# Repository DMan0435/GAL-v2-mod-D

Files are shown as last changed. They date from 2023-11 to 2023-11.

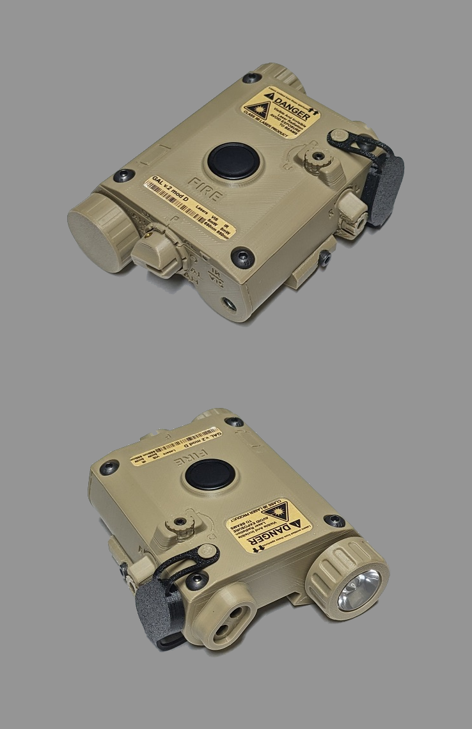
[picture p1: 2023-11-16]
IMAGES/GAL_v2 mod d 1.png

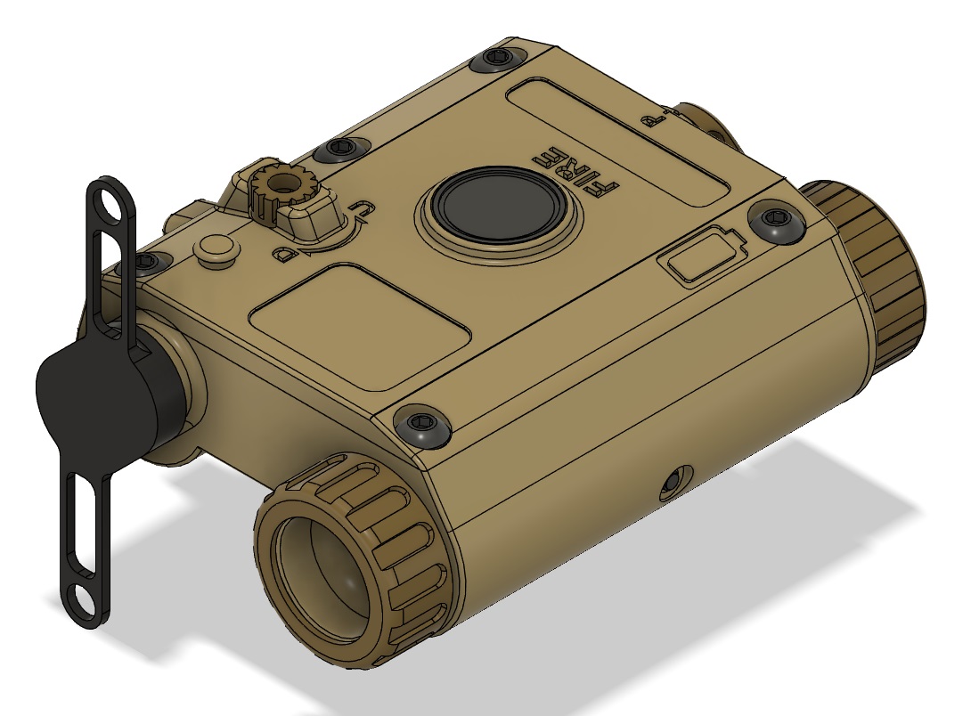
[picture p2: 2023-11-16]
IMAGES/img3.jpg

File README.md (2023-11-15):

# GAL-v2-mod-D

This is a modification of Knack Tactical's GAL V2 LAM project, found here: https://github.com/knack-tactical/GAL

This version requires several different components to be built, and custom 3D printed models found here.  Read the parts list and build guide documents for information on what you need.  If you have Knack's parts kit, many of the included parts can be used in this design as well.

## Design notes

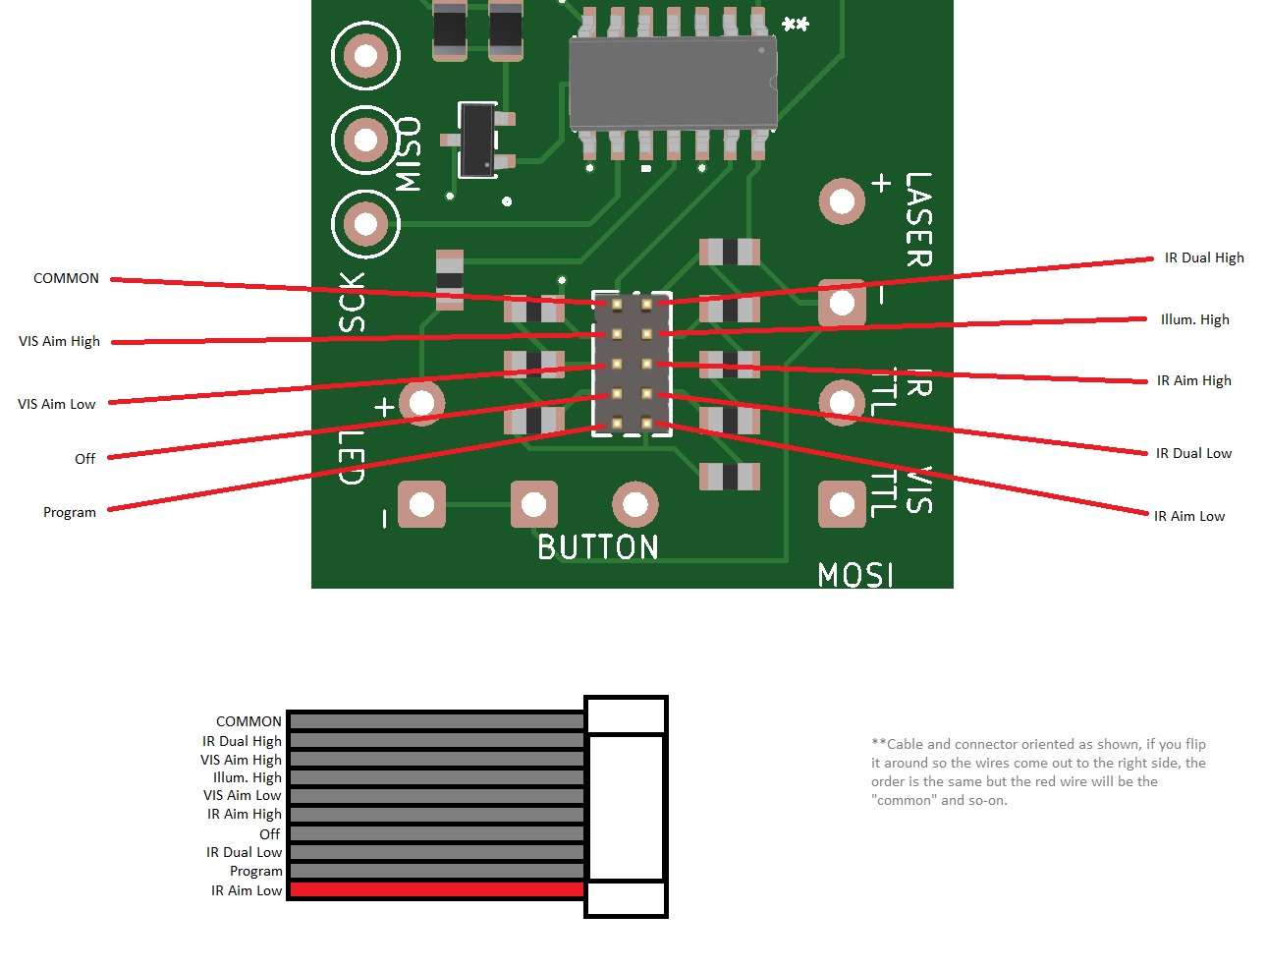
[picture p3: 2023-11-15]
PCB/GALv2modD_Custom_PCB_pinout.jpg

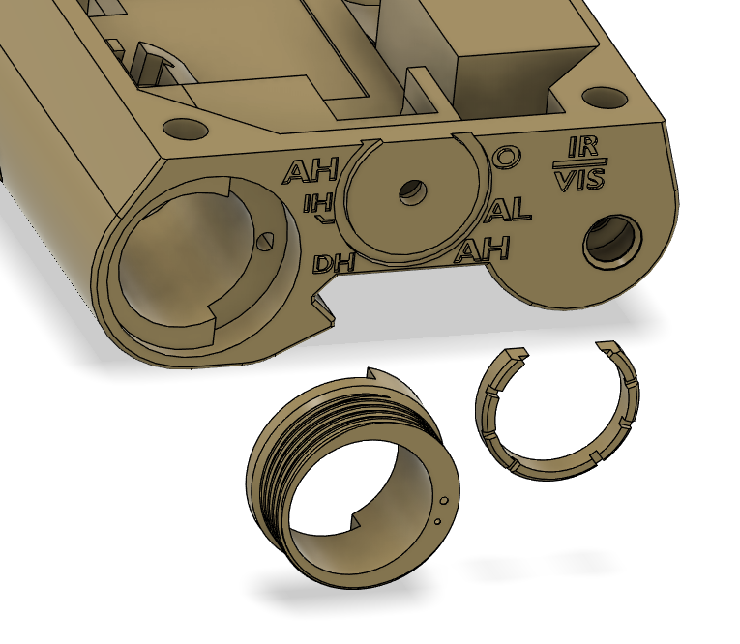
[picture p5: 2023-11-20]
IMAGES/Option3.png

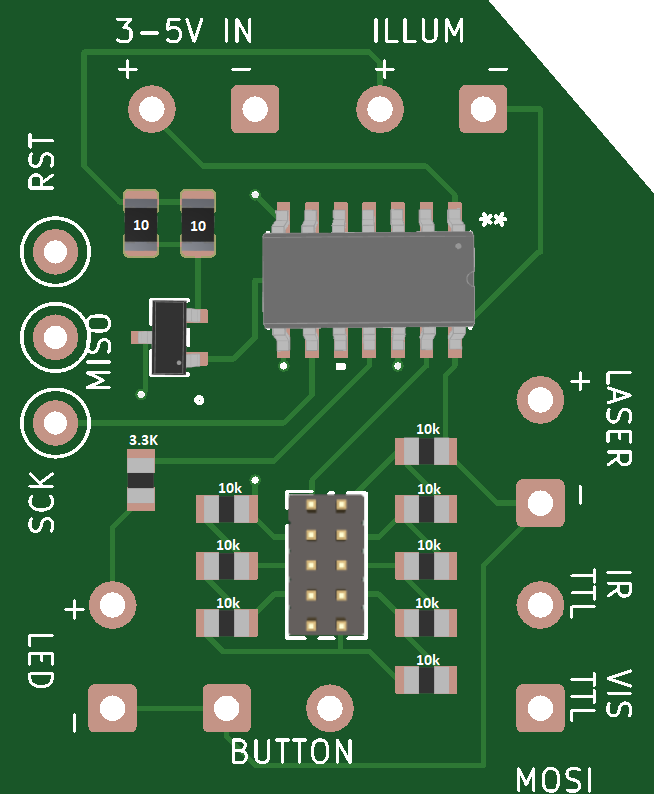
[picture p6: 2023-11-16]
PCB/GALv2modD_PCB_Layout.png

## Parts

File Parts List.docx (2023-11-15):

GAL v.2 mod D - Parts List

11/15/23

Items indicated with an (*) differ from parts in Knack’s kit.

Hardware

* 5x M4x6mm Button Head Hex Drive Screw - Securing Lid to Body

* 5x M4x4mm Short Threaded Heatset Inserts - Securing Lid to Body

* 1x M3x70mm Socket Head Screw - Pic Rail Screw

2x M3x12mm Flat-Tip Set Screw - Laser Adjustment Screw

2x M3 Hex Nut - Laser Adjustment Lock

3x M3x4mm Short Threaded Heatset Inserts - Laser Adjustment, Pic Rail Nut

* 1x M2x4mm Short Threaded Heatset Insert – Mode Selector Knob Retainer

* 1x M2x4mm Flat Tip Screw - Mode Selector Knob Retainer

2x AAA Negative (Spring) Battery Terminal - Negative terminal for battery, rear spring for laser

1x 0.5'' x 0.148'' OD Compression Spring - Laser retention spring

Various Lengths of thin wire (20 to 28 AWG)

1x 3.5'' of 18 to 22 AWG Solid Core Wire or Enamel Wire

1x 21mm dia. x 1-2mm thick Copper Disc

1x AAA Positive Battery Terminal - For battery positive terminal

1x Laser Hole Cover - Covers the Laser Hole

This can be laser cut/CNC’d from 1/16” polycarbonate or acrylic, or made by hand

1x 6.1mm ID Unthreaded Spacer - 1st Stage of Crane Connector

1x 0.198'' ID Unthreaded Spacer - 2nd Stage of Crane Connector

Electrical Components

* 1x Momentary Press Button – Schurter 1241.1104.7097 - Activation Button

* 1x Momentary Press Button Bolt Down Kit – Schurter 0098.9201- Secures Activation Button

* 1x Rotary Switch – Grayhill 56P36-01-1-09N - Mode Selection

1x 940nm or 850nm 3W LED - Illuminator LED

1x 20mm Lens for 3W LED (various beam angles) - Illuminator LED Lens

1x 850nm 6x23mm TTL Driven Laser - IR Laser

1x 650nm 6x23mm TTL Driven Laser - Visible Laser

1x Diffused 2mm Flat Top LED - Indicator LED

Control board

1x Custom PCB:

1x ATTINY84A-SSU-ND

1x MMBT2222ATPMSCT-ND

8x RES 10K OHM 5% 1/8W 0805 (RC0805JR-0710KL)

2x RES 10 OHM 1% 1/4W 0805 (RC0805FR-7W10RL)

1x RES 3.3K OHM 1% 1/8W 0805 (RC0805FR-073K3L)

1x Connector HEADER VERT 10POS 1.27MM (20021111-00010T4LF)

1x Connector SOCKET 10POS IDC GOLD (3230-10-0101-00)

1ft. 0.635mm (0.025") Pitch 10-Wire, 10 Conductors IDC Flat Ribbon Cable for 1.27mm 10POS Connector

** Arduino Uno and jumper wires to connect to PCB and program the ATTINY84A **

--OR—

1x KNACK GAL V2.2 PCB with lead wires from rotary switch to board positions, this board is pre-built with components and the ATTINY84A is already programmed.

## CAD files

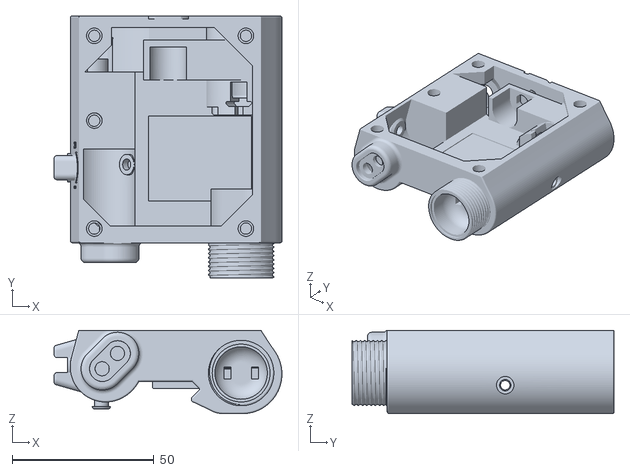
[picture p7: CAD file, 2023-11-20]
STL/Main Body Option 3/GAL v2 mod D - MAIN BODY (seperate batt thread and switch fence).stl
80.4 x 92.4 x 29.4

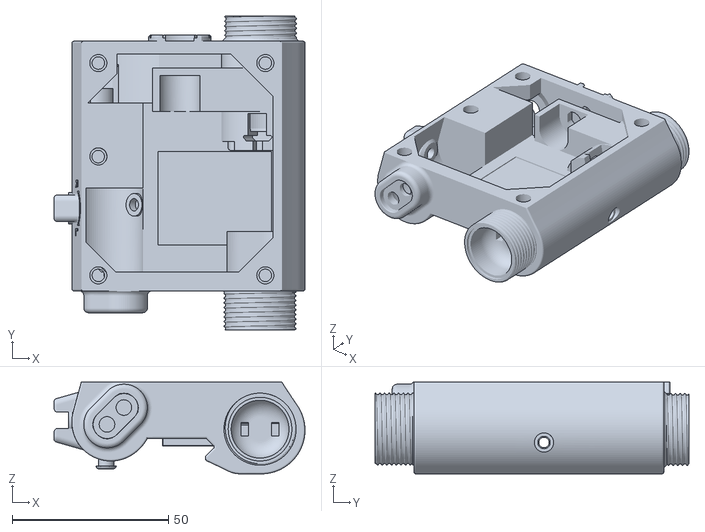
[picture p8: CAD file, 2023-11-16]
STL/GAL v2 mod D - MAIN BODY (one piece).stl
80.4 x 100.4 x 29.4

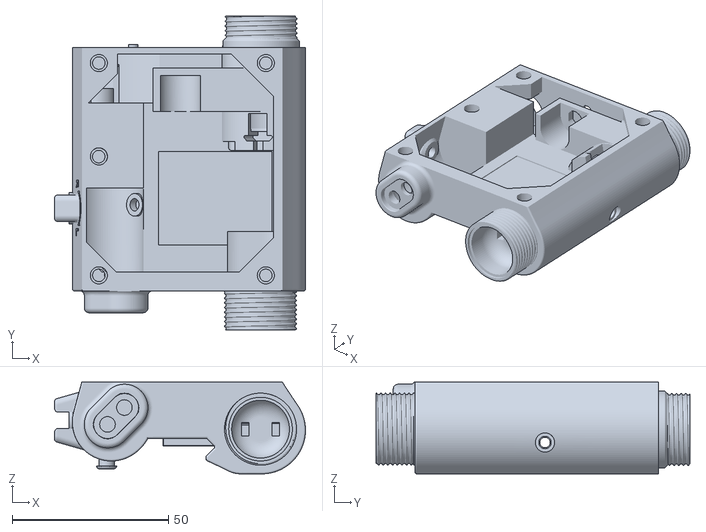
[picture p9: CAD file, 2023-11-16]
STL/GAL v2 mod D - MAIN BODY (detached backplate).stl
80.4 x 100.4 x 29.4

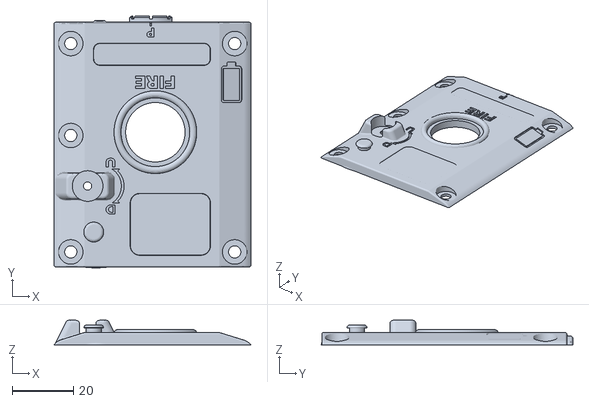
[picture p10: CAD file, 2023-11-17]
STL/GAL v2 mod D - LID (Knack Kit Button).stl
64.3 x 82.3 x 8.00

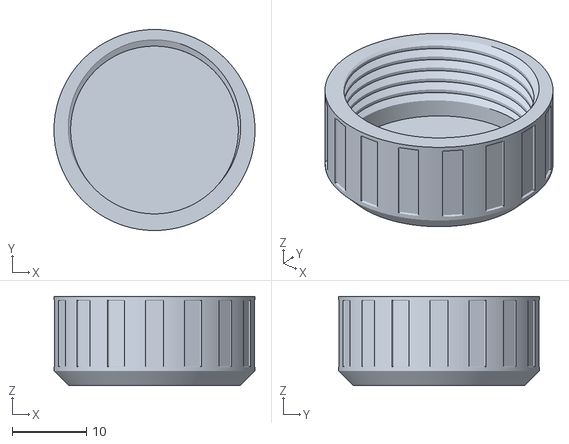
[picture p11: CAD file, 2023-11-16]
STL/GAL v2 mod D - BATTERY CAP (nickel).stl
27.0 x 27.0 x 12.0

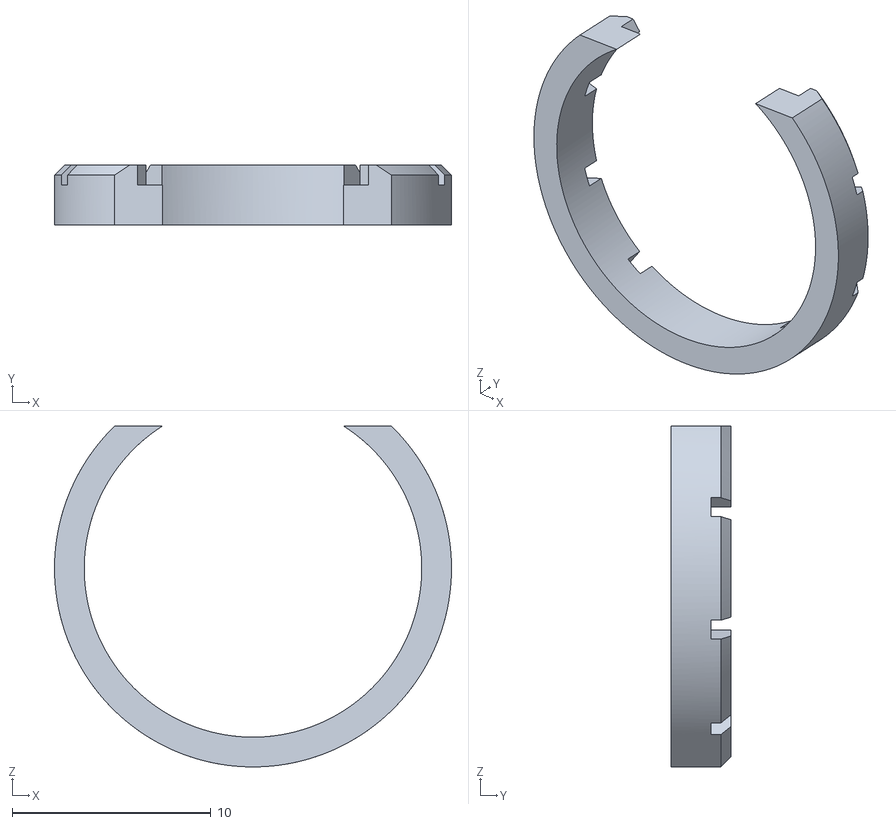
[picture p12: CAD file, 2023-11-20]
STL/Main Body Option 3/GAL v2 mod D - SWITCH FENCE.stl
20.0 x 3.00 x 17.2

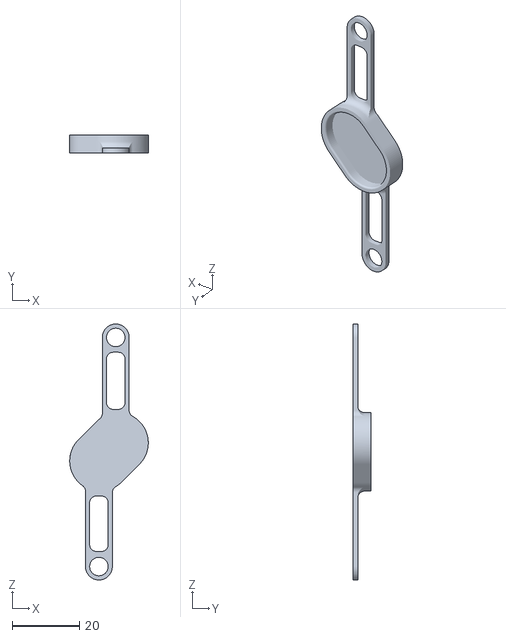
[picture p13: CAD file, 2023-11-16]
STL/GAL v2 mod D - TPU LASER COVER.stl
23.4 x 5.50 x 76.2

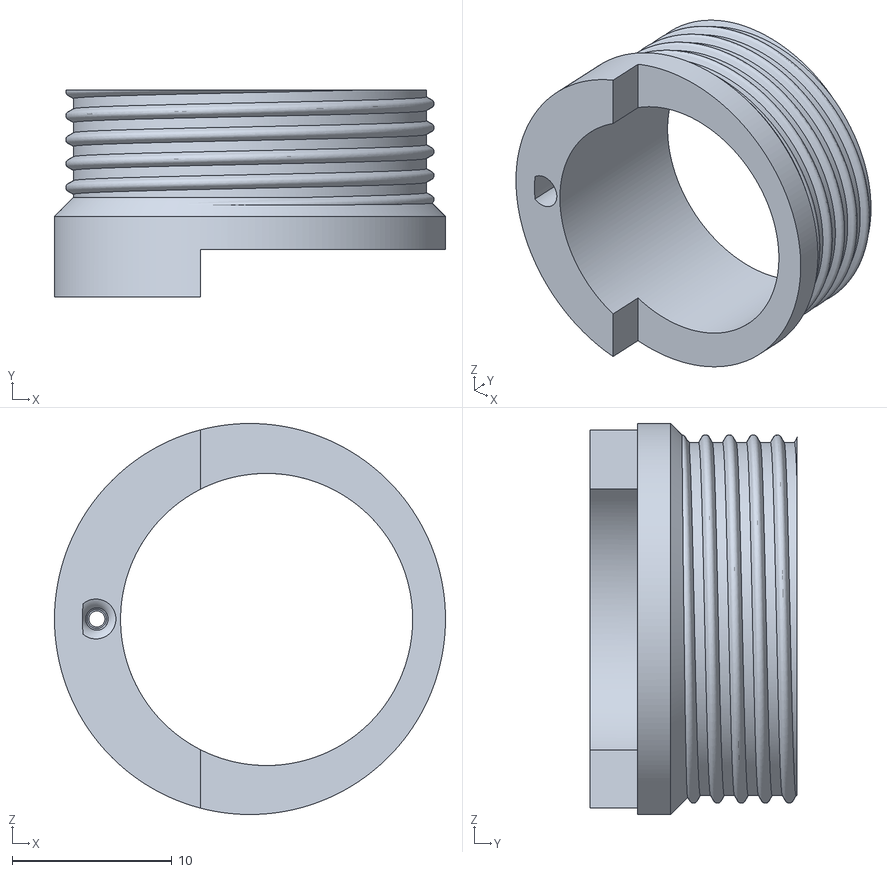
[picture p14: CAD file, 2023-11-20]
STL/Main Body Option 3/GAL v2 mod D - BATT THREADED INSERT.stl
24.5 x 13.0 x 24.5

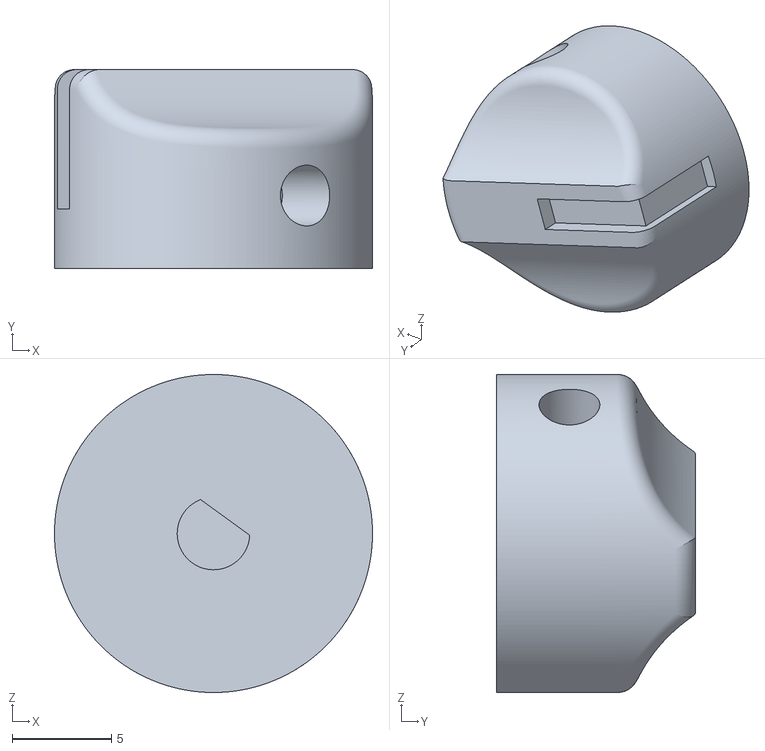
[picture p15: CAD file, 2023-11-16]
STL/GAL v2 mod D - SWITCH KNOB.stl
16.0 x 10.0 x 16.0

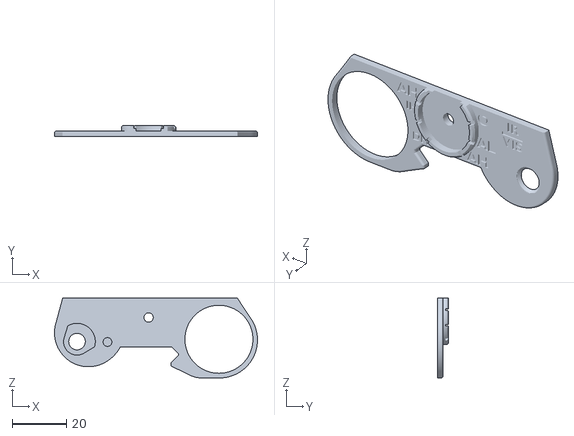
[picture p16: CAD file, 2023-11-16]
STL/GAL v2 mod D - BACKPLATE.stl
74.7 x 4.00 x 29.4

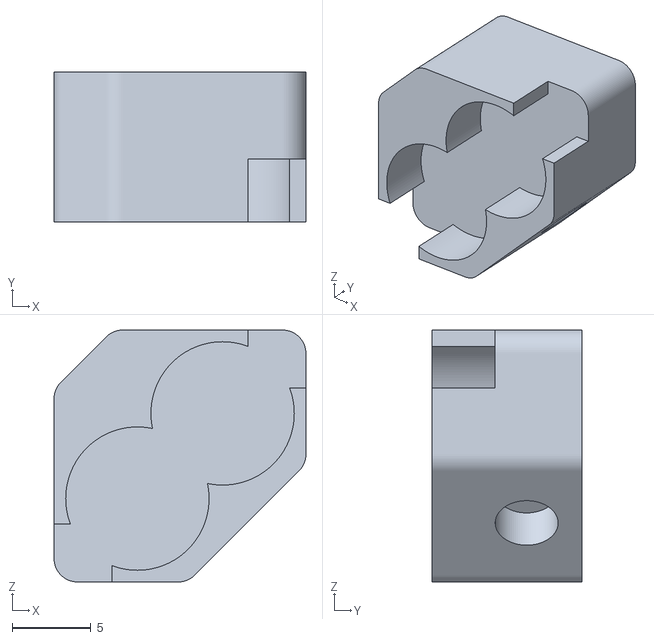
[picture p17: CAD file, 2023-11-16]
STL/GAL v2 mod D - LASER BASE.stl
16.0 x 9.50 x 16.0

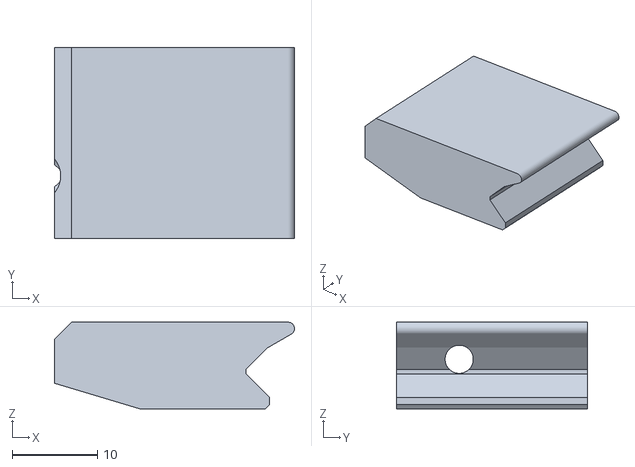
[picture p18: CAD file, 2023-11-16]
STL/GAL v2 mod D - RAIL CLAMP.stl
28.2 x 22.4 x 10.2

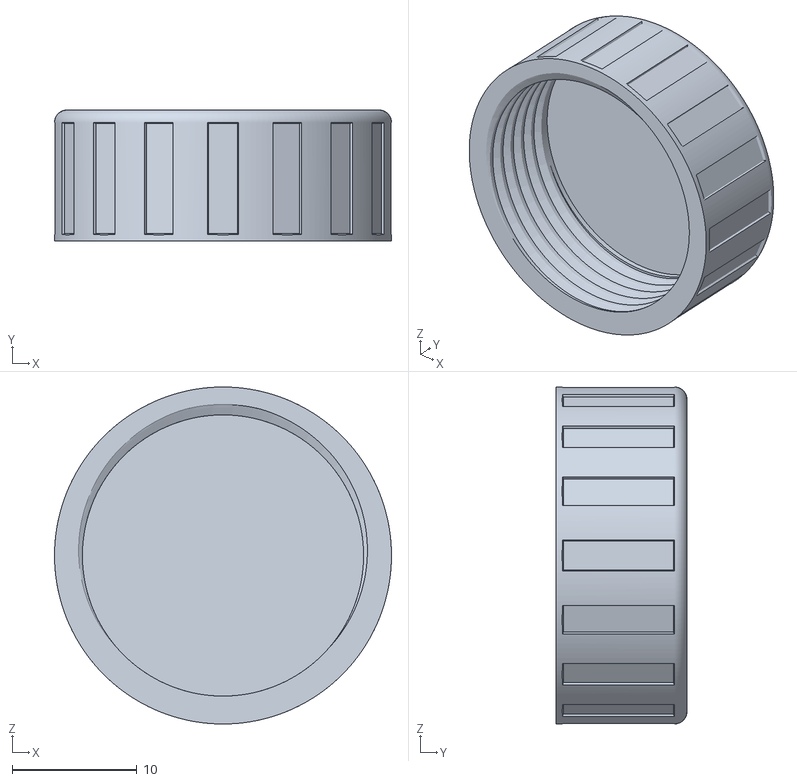
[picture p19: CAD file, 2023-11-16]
STL/GAL v2 mod D - BATTERY CAP (thin disk).stl
27.0 x 10.5 x 27.0

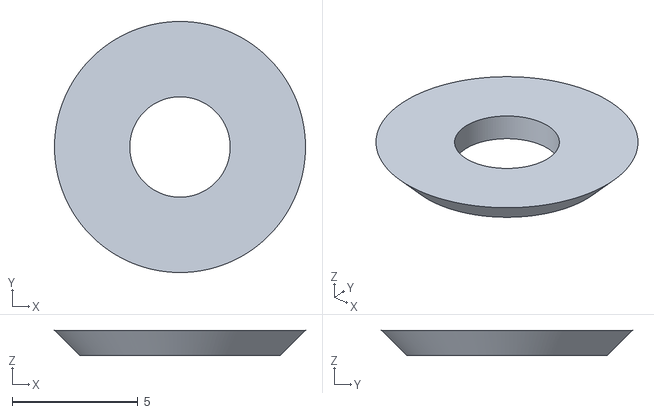
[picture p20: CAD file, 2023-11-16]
STL/GAL v2 mod D - ELEVATION SUPPORT.stl
10.00 x 10.00 x 1.00

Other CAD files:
STL/GAL v2 mod D - LASER HOUSING.stl
STL/GAL v2 mod D - LID (18mm Button).stl
STL/GAL v2 mod D - ZERO LOCK NUT.stl

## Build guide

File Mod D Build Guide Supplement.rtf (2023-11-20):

GAL v.2 mod D Build Guide Supplement
11/19/23

**Read through Knack's original build guide for instruction on basic assembly concepts and best print orientations.

- Unique Part Print Orientations:
-Backplate printed flat with letters facing up.
-Switch Knob printed with bottoim down.
-TPU Laser Cover printed front face down

-Main Body Variations:

There are Three options with the main body. Either you print the complete one piece body and deal with potential poor resolution in the mode selector markings on the back, or you print the two-part body with the seperate backplate, or option 3 is to print a version with a seperate part for the battery compartment threads and the fence around the switch on the back that you glue on after. If you do the two-part one, you'll want to install the crane connector parts with wires attached first before you attach the back plate or else there won't be clearance to install them later. To attach the plate, run a bead of super glue around all edges to bond the parts. Use the selector rotary switch axel to aid inalignement. Option 3 gives you the ability to put the back face flat on the print bed, then glue on the other two parts after printing everything.
For either version, print the body with the front side facing up, and use generous tree-supports to make sure all the internal overhangs are supported.

-Battery Cap Variations:

There are two battery cap options. One is the original Knack design that uses a US nickel installed inside. The other I moddified to use a thin metal disk instead. For that disc, I bought a small sheet of copper from a hobby store, traced out a nickle sized disc and cut it out.

-PCB Options:

You may either use the PCB supplied in Knack's kit or have the modified version I designed made using the included PCB design zip file. JLCPCB is a good option for quick and cheap custom PCBs if you go that route. Also, with the custom board, you will have to buy and solder down all the small components as well, so keep that in mind. There is a reference image to help there, as well as an explination of the switch-to-board wiring.

-New Rotary Switch:

The smaller 9-position Grayhill 56P36-01-1-09N switch is installed in the rear of the body. It can only go in one of two orientations thanks to the flats on the threaded barrel, so confirm you have it pointing the right way so that with the knob installed, it points at the positions on the body and isn't upside-down. You may have to remove the sticker on the side with the pin ID numbers to install it, it's a tight fit.
Here is the pin-out for the new switch:
Pin 1 - IR Dual High (DH)
Pin 2 - IR Illum Only High (IH)
Pin 3 - IR Aim High (AH)
Pin 4 - IR Dual Low (DL)
Pin 5 - PROGRAM (P)
Pin 6 - IR Aim Low (AL)
Pin 7 - OFF (O)
Pin 8 - Vis Aim Low (AL)
Pin 9 - Vis Aim High (AH)
Pin 10 - UNUSED
Center Pin - COMMON

*Note: I swapped the positions of the "Program" and "IR Aim Low" modes vs. Knack's design, so pins 4 and 5 are swapped if using his PCB. The correct positions are marked on the image titled "Knack PCB retrofit wiring diagram".

Once the new switch is installed with it's retaining but inside the body, the printed selector knob can be slide on. Install the M2 heat set in the hole on the side of the knob and use the M2 grub screw to secure the knob in place on the switch.

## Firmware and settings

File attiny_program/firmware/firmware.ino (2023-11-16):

#include <avr/interrupt.h>
#include <avr/sleep.h>
#define time_t unsigned long

// Pin Variables
int rotarySwitch = A0;
int vis = 6;
int ir = 7;
int illum = 8;
int buttonPin = 1;
int indicator = 2;

// PWM Variables
int numSteps = 8;
float threshold = 1024.0 / numSteps;

// Programming
bool programming = false;
int blinkSpeed = 100; // ms between blink state changes
bool buttonPressed = false;

// Brightness Settings
int brightPct = 100;
int dimPct = 20;
float b = brightPct / 100.0 * 255;
float d = dimPct / 100.0 * 255;
//                // VH,     VL,  O, AL,  DL,  AH,     IH,     DH,     P
//int visVal[9] =   {bright, dim, 0, 0,   0,   0,      0,      0,      0};
//int irVal[9] =    {0,      0,   0, dim, dim, bright, 0,      bright, 0};
//int illumVal[9] = {0,      0,   0, 0,   dim, 0,      bright, bright, 0};
//int ppsVal[9] =   {0,      0,   0, 0,   1,   2,      4,      8,      0};

                // P  DH  IH  AH  DL  AL  O  VL  VH
int visVal[9] =   {0, 0,  0,  0,  0,  0,  0, d,  b};
int irVal[9] =    {0, b,  0,  b,  d,  d,  0, 0,  0};
int illumVal[9] = {0, b,  b,  0,  d,  0,  0, 0,  0};
int ppsVal[9] =   {0, 8,  4,  2,  1,  0,  0, 0,  0};
int programPos = 0;

// Illum Settings
int pulsePerSec = 0;
int flashRate, flashRateBase = 1000;
float illumBrightness;
time_t timeout = 30500; // sec until button press times out
int timeout_count_limit = 10, timeout_count = 0;
time_t current_t = 0;
bool doIllumLoop = false;
time_t currentMillis, previousMillis = 0;
int illumState = illumBrightness;

// Double click variables
int dblPressInterval = 250; // max ms between clicks to enable double-press-to-hold
time_t dblDownTime = 0;
bool dblPressed = false;
time_t sleepTimeout = 300; // ms until sleep

///////////////////////////////
///        Interrupt        ///
///////////////////////////////

ISR(PCINT0_vect) {
  current_t = millis();
  noInterrupts();
  timeout_count = 0;
  if (!digitalRead(buttonPin)) { // Button Pressed
    if (!buttonPressed) { // This prevents multiple interrupts
      if (current_t - dblDownTime < dblPressInterval && current_t > dblPressInterval) { 
        dblPressed = true;
      } else {
        dblPressed = false;
      }
      dblDownTime = current_t;
      buttonPressed = true;
      digitalWrite(indicator, HIGH);
      setOutputs();
    }
  } else {
    if (programming) {
      getPulsePerSec();
      programming = false;
    }
    buttonPressed = false;
    if (!dblPressed) {
      doIllumLoop = false;
      analogWrite(vis, 0);
      analogWrite(ir, 0);
      analogWrite(illum, 0);
      digitalWrite(indicator, LOW);
    }
  }
  interrupts();
}

//////////////////////////////
///      Setup & Loop      ///
//////////////////////////////

void setup() {
  pinMode(buttonPin, INPUT_PULLUP);
  pinMode(indicator, OUTPUT);
  GIMSK = 0b00010000;
  PCMSK0 = 0b00000010;
  set_sleep_mode(SLEEP_MODE_PWR_DOWN);
}

void loop() {
  if ((buttonPressed || dblPressed) && doIllumLoop ) {
    currentMillis = millis();
    if (currentMillis - previousMillis >= flashRate) {
      previousMillis = currentMillis;
      illumState = (illumState == 0) ? illumBrightness : 0;
      analogWrite(illum, illumState);
    }
  }
  if (millis() - current_t >= timeout) {
    current_t = millis();
    timeout_count++;
  }
  if ((!buttonPressed && !dblPressed) || timeout_count >= timeout_count_limit ) {
//    analogWrite(vis, 0);
//    analogWrite(ir, 0);
//    analogWrite(illum, 0);
//    digitalWrite(indicator, LOW);
    dblPressed = false;
    if (millis() - current_t >= sleepTimeout) {
      sleep_mode();
    }
  }
}

///////////////////////////////
///      Rotary Switch      ///
///////////////////////////////

int getRotaryPos() {
  float switchValFlt = round(analogRead(rotarySwitch) / threshold);
  int val = switchValFlt;
  return val;
}

void setOutputs() {
  int pos = getRotaryPos();
  analogWrite(vis, visVal[pos]);
  analogWrite(ir, irVal[pos]);
  illumBrightness = illumVal[pos];
  if (pos == programPos) {
    analogWrite(illum, illumBrightness);
    program();
    return;
  }

  if (pulsePerSec == 0) {
    analogWrite(illum, illumBrightness);
  } else { // Set up illum flashing
    if (illumBrightness != 0) {
      doIllumLoop = true;
    }
  }
}

///////////////////////////////
///       Programming       ///
///////////////////////////////

void program() {
  programming = true;
  blinkIndicator(1, true);
  // Wait 5 sec, cancel otherwise
  interrupts();
  time_t t = millis();
  while (programming) {
    if (millis() - t >= 5000) {
      analogWrite(vis, 0);
      analogWrite(ir, 0);
      analogWrite(illum, 0);
      digitalWrite(indicator, LOW);
      pulsePerSec = 0;
      break;
    }
  }
  programming = false;
}

void getPulsePerSec() {
  pulsePerSec = ppsVal[getRotaryPos()];
  if (pulsePerSec != 0) {
    flashRate = flashRateBase / (2 * pulsePerSec);
    blinkIndicator(pulsePerSec, false);
  }
}

void blinkIndicator(int blinkNum, bool endHigh) {
  int count = 0;
  bool blinkState = digitalRead(indicator), buttonPressed_ = buttonPressed;
  interrupts();
  time_t currentMillis, previousMillis = millis();
  int stateChanges = (2*blinkNum) - endHigh + blinkState;
  while (count < stateChanges && buttonPressed_ == buttonPressed) {
    currentMillis = millis();
    if (currentMillis - previousMillis >= blinkSpeed) {
      previousMillis = currentMillis;
      blinkState = !blinkState;
      digitalWrite(indicator, blinkState);
      count++;
    }
  }
}
